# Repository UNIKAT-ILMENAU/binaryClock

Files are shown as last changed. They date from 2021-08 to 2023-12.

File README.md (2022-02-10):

# Notizen

## Idee

- QRCode mit Link auf Webseite für Flackercode Config Tool
- vllt Pads für I2C und ISP rausführen
- auf PCB, welche LED welcher Modus ist
- Comic Design? (muss zu Skyline passen)

## Hardware
- Fotodioden/transistoren
    - SFH 229 OSO
    - SFH 203
    - PT 334-6C EVL
    - SFH 309-5 OSO
    - SFH 300-3/4
- Batteriehalter: https://www.mouser.de/ProductDetail/Linx-Technologies/BAT-HLD-012-SMT?qs=Z0V%2FpEl%252BOGfZsSJil9WIXw%3D%3D
- Micro USB Port: https://www.mouser.de/ProductDetail/CUI-Devices/UJ2-MIBH-G-SMT-TR?qs=IS%252B4QmGtzzpvS1XQusp0iA%3D%3D

## Lötreihenfolge
- Quartz
- Widerstände
- LED
- Taster
- Sockel
- Kondensatoren

## Software
- https://forum.arduino.cc/t/time-libary-sommerzeit-winterzeit/221884

### Modi
Button 1: Select
Button 2: Plus
Button 3: Minus

Select rotiert durch die Zustände, Plus und Minus verändern den Wert

- TimeRunning, Zeit wird angezeigt und zählt          
- MenuYear, Jahr setzen
- MenuMonth, Monat setzen
- MenuDay, Tag setzen
- MenuHour, Stunden setzen
- MenuMinute, Minuten setzen
- MenuSecond, Sekunden setzen 

## ADC Calculation
| No. Switches | 3 | | Button No. | Req'd ADC | Req'd V (R1) | Req'd V (R2+) | Req'd R | Closest R | Actual V (R1) | Actual V (R2+) | Actual ADC | Diff from prev. | In Tolerance | Current (mA) |
|---|---:|---|---:|---:|---:|---:|---:|---:|---:|---:|---:|---:|---:|---:|
| ADC Resolution  | 1024 | | 0 | 1024 | 0.00 | 5.00 | 47000 | 47000 | 5.00 | 0.00 | 0 | 0 | N/A | 0.11 |
| Tolerance (%) | 2 | | 1 | 341 | 3.33 | 1.67 | 23500 | 24000 | 3.31 | 1.69 | 346 | 346 | YES | 0.07 |
| Voltage | 5 | | 2 | 683 | 1.67 | 3.33 | 70500 | 68000 | 1.69 | 3.31 | 678 | 332 | YES | 0.04 |
| | | | 3 | | | | | | | | | | | |
| | | | 4 | | | | | | | | | | | |
| | | | 5 | | | | | | | | | | | |
| | | | 6 | | | | | | | | | | | |
| | | | 7 | | | | | | | | | | | |
| ADC Tolerance | 20.48 |  (+/-) | 8 | | | | | | | | | | | |
| Std. Deviation  | 10.27164132 | | 9 | | | | | | | | | | | |
| | | | 10 | | | | | | | | | | | |
| | | | 11 | | | | | | | | | | | |

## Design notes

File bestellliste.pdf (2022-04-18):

Tabelle1

Seite 1

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

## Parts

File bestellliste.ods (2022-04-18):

Teil | Händler | Händlerbez./Bestellnr. |  | Stückzahl | Kosten pro Shop |  | mit MwSt | Versand
BAT-HLD-012-SMT | Digi-Key | BAT-HLD-012-SMT-ND | -> LINK | 120 | Digi-Key | 393,668 | 468,46492 | 0
ATTINY84V-10PU | Digi-Key | ATTINY84V-10PU-ND | -> LINK | 120 | Highlight-led | 227,63 | 227,63 | 0
Micro-usb-port | Digi-Key | UJ2-MIBH-G-SMT-TR | -> LINK | 120 | Reichelt | 43,8 | 43,8 | 5,59
PT 204-6C | Digi-Key | 1080-1152-ND | -> LINK | 100 | RS | 95,24 | 113,3356 | 0
82Ω Widerstand | Digi-Key | CFM12JT82R0 | -> LINK | 400
4.7kΩ Widerstand | Digi-Key | CFM12JT4K70 | -> LINK | 200
10k | Digi-Key | CFM12JT10K0 | -> LINK | 100
47k | Digi-Key | CFM12JT47K0 | -> LINK | 100 |  | Kosten Gesamt (geschätzt!)
24k | Digi-Key | CFM12JT24K0 | -> LINK | 100 |  | 858,82052
68k | Digi-Key | CFM12JT68K0 | -> LINK | 100
6x6mm Taster | Digi-Key | 2223-TS02-66-50-BK-160-SCR-D-ND | -> LINK | 300
LED | Highlight-led | WTN-5-3600ww | -> LINK | 1700
Mini Quarz | Reichelt | 0,032768 | -> LINK | 100
15pF Kondensator | Reichelt | KERKO-500 15p | -> LINK | 100
100nF Kondensator | Reichelt | HITA SF1H104Z-L5 | -> LINK | 200
Sockel DIL 14 | Reichelt | GS 14 | -> LINK | 120
Sockel DIL 8 | Reichelt | GS 8 | -> LINK | 120
MCP7940N-I/P | RS | 165-2125 | -> LINK | 120
18pF Kondensator | RS | 852-3312 | -> LINK | 100

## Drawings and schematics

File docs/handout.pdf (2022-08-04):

# UNIKAT - Binäruhr

## Widerstände

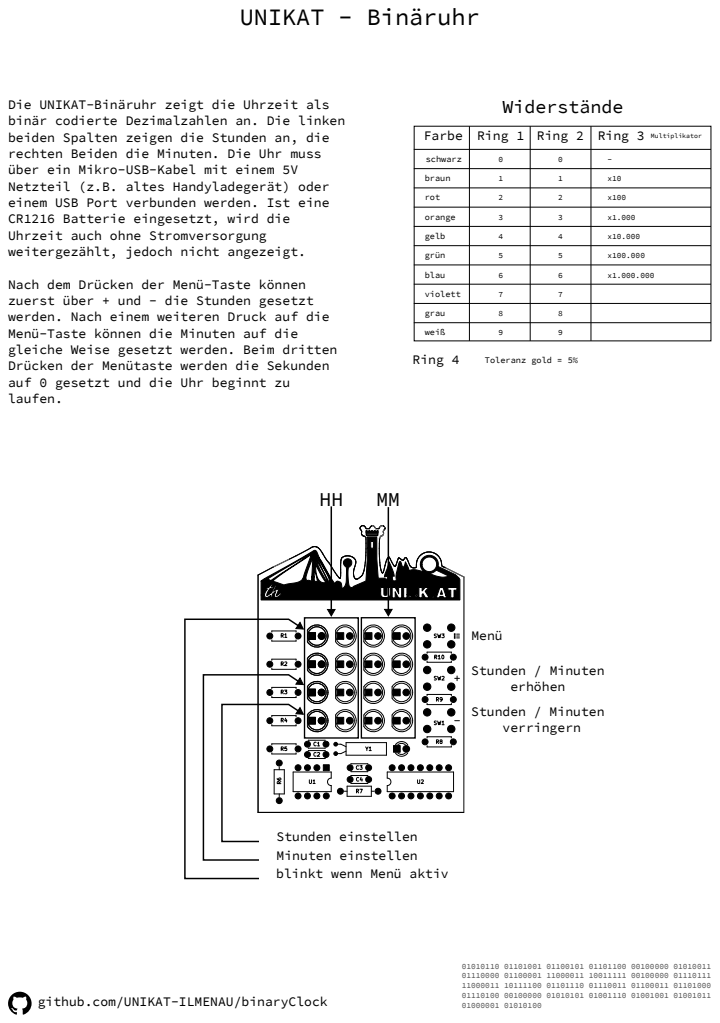
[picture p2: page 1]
Ring 4; Toleranz gold = 5%; Farbe; Ring 1; Ring 2; Multiplikator; schwarz; braun; rot; orange; gelb; grün; blau; violett; grau; weiß; Ring 3; Menü; Stunden / Minuten erhöhen; Stunden / Minuten verringern

Die UNIKAT-Binäruhr zeigt die Uhrzeit als
binär codierte Dezimalzahlen an. Die linken
beiden Spalten zeigen die Stunden an, die
rechten Beiden die Minuten. Die Uhr muss
über ein Mikro-USB-Kabel mit einem 5V
Netzteil (z.B. altes Handyladegerät) oder
einem USB Port verbunden werden. Ist eine
CR1216 Batterie eingesetzt, wird die
Uhrzeit auch ohne Stromversorgung
weitergezählt, jedoch nicht angezeigt.

Nach dem Drücken der Menü-Taste können
zuerst über + und - die Stunden gesetzt
werden. Nach einem weiteren Druck auf die
Menü-Taste können die Minuten auf die
gleiche Weise gesetzt werden. Beim dritten
Drücken der Menütaste werden die Sekunden
auf 0 gesetzt und die Uhr beginnt zu
laufen.

Stunden einstellen
Minuten einstellen
blinkt wenn Menü aktiv

github.com/UNIKAT-ILMENAU/binaryClock

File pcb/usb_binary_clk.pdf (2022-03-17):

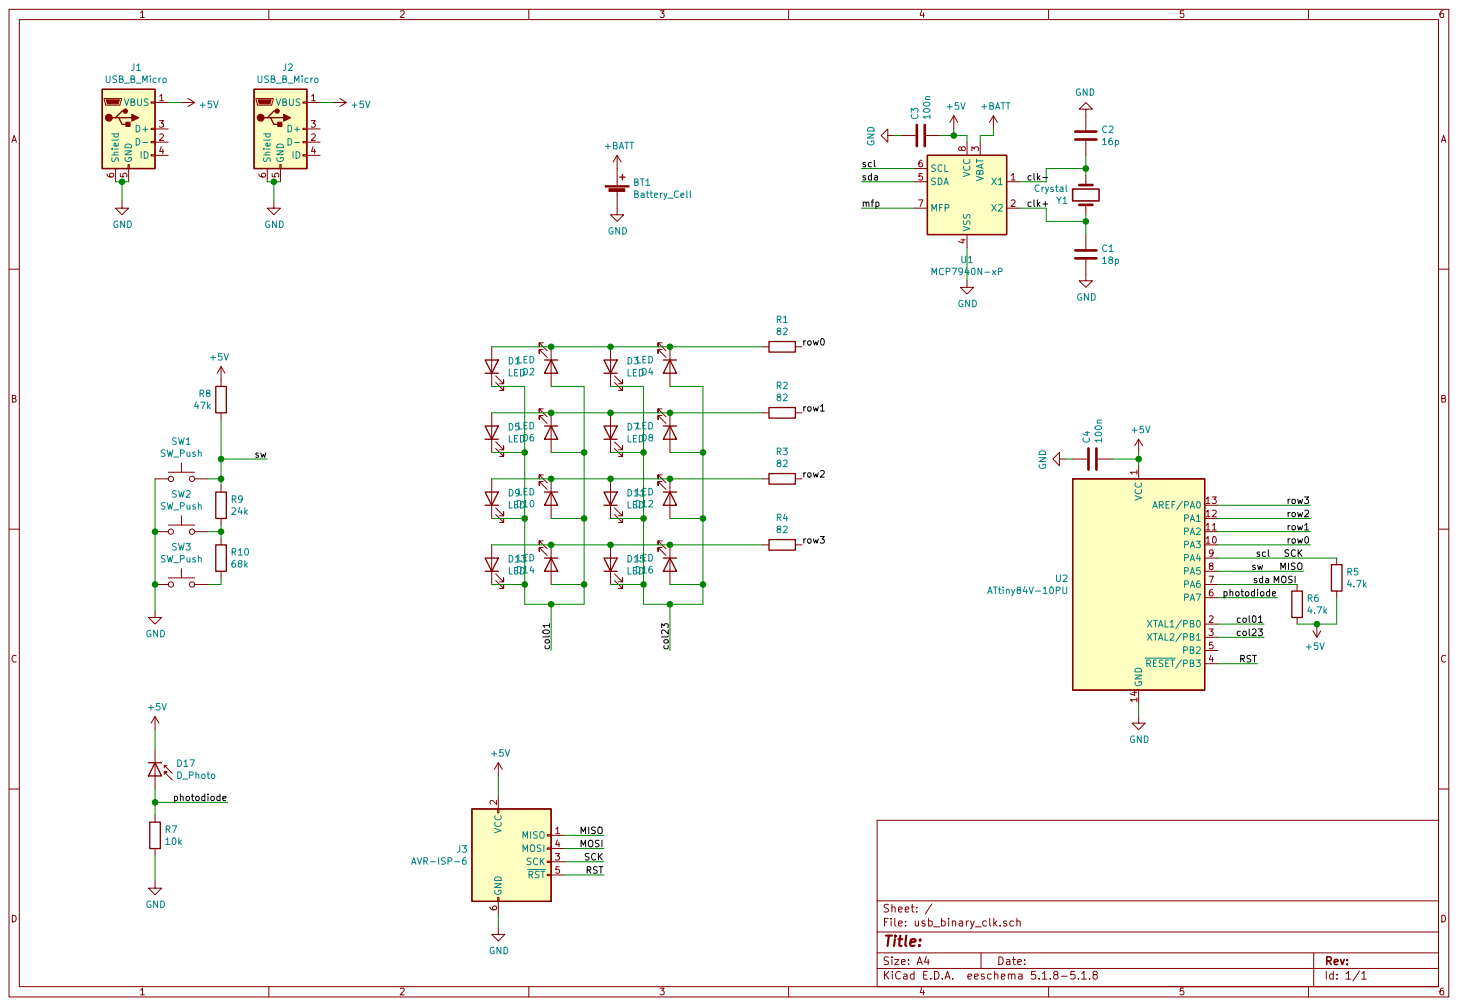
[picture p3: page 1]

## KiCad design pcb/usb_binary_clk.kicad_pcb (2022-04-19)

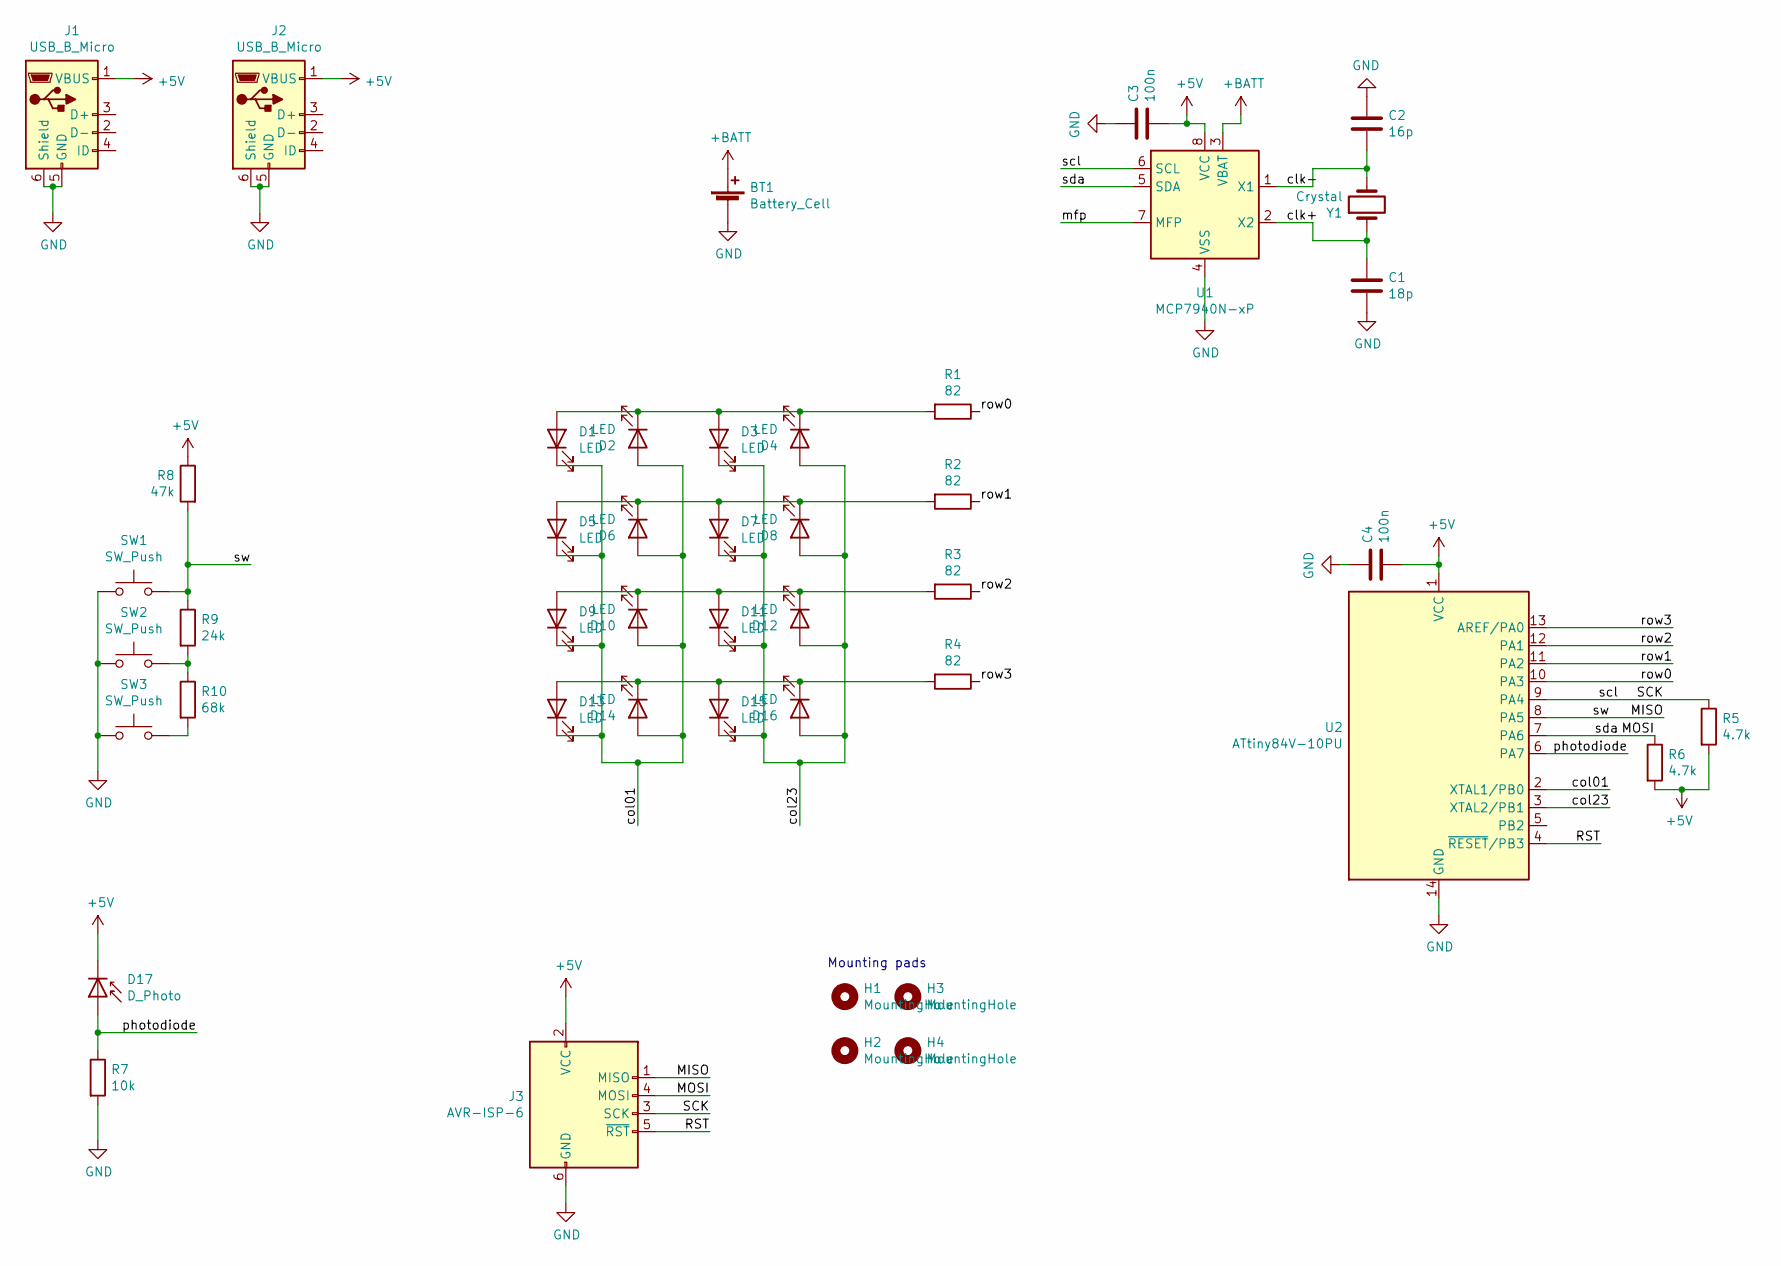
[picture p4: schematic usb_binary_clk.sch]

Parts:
BT1: Battery_Cell; bat-hld-012
C1: 18p; C_Disc_D4.3mm_W1.9mm_P5.00mm
C2: 16p; C_Disc_D4.3mm_W1.9mm_P5.00mm
C3, C4: 100n; C_Disc_D4.3mm_W1.9mm_P5.00mm
D1, D2, D3, D4, D5, D6, D7, D8, D9, D10, D11, D12, D13, D14, D15, D16: LED; LED_D5.0mm
D17: D_Photo; LED_D3.0mm
H1, H2, H3, H4: MountingHole; mountingPad_custom1
J1, J2: USB_B_Micro; UJ2MIBHGSMTTR
J3: AVR-ISP-6; isp_pogoPinPads
R1, R2, R3, R4: 82; R_Axial_DIN0207_L6.3mm_D2.5mm_P7.62mm_Horizontal
R5: 4.7k; R_Axial_DIN0207_L6.3mm_D2.5mm_P7.62mm_Horizontal
R6: 4.7k; R_Axial_DIN0207_L6.3mm_D2.5mm_P10.16mm_Horizontal
R7: 10k; R_Axial_DIN0207_L6.3mm_D2.5mm_P10.16mm_Horizontal
R8: 47k; R_Axial_DIN0207_L6.3mm_D2.5mm_P7.62mm_Horizontal
R9: 24k; R_Axial_DIN0207_L6.3mm_D2.5mm_P7.62mm_Horizontal
R10: 68k; R_Axial_DIN0207_L6.3mm_D2.5mm_P7.62mm_Horizontal
SW1, SW2, SW3: SW_Push; SW_PUSH_6mm_H4.3mm
U1: MCP7940N-xP; DIP-8_W7.62mm
U2: ATtiny84V-10PU; DIP-14_W7.62mm
Y1: Crystal; Crystal_AT310_D3.0mm_L10.0mm_Horizontal

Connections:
+5V: C3.2, C4.2, D17.1 (K), J1.1 (VBUS), J2.1 (VBUS), J3.2 (VCC), R5.2, R6.2, R8.1, U1.8 (VCC), U2.1 (VCC)
+BATT: BT1.1 (+), U1.3 (VBAT)
/MISO: J3.1 (MISO), R8.2, R9.1, SW1.1, U2.8 (PA5)
/MOSI: J3.4 (MOSI), R6.1, U1.5 (SDA), U2.7 (PA6)
/RST: J3.5 (~RST), U2.4 (~RESET~/PB3)
/SCK: J3.3 (SCK), R5.1, U1.6 (SCL), U2.9 (PA4)
/clk+: C1.1, U1.2 (X2), Y1.1
/clk-: C2.2, U1.1 (X1), Y1.2
/col01: D1.1 (K), D2.2 (A), D5.1 (K), D6.2 (A), D9.1 (K), D10.2 (A), D13.1 (K), D14.2 (A), U2.2 (XTAL1/PB0)
/col23: D3.1 (K), D4.2 (A), D7.1 (K), D8.2 (A), D11.1 (K), D12.2 (A), D15.1 (K), D16.2 (A), U2.3 (XTAL2/PB1)
/mfp: U1.7 (MFP)
/photodiode: D17.2 (A), R7.1, U2.6 (PA7)
/row0: R1.1, U2.10 (PA3)
/row1: R2.1, U2.11 (PA2)
/row2: R3.1, U2.12 (PA1)
/row3: R4.1, U2.13 (AREF/PA0)
GND: BT1.2 (-), C1.2, C2.1, C3.1, C4.1, J1.5 (GND), J1.6 (Shield), J2.5 (GND), J2.6 (Shield), J3.6 (GND), R7.2, SW1.2, SW2.2, SW3.2, U1.4 (VSS), U2.14 (GND)
unnamed: D1.2 (A), D2.1 (K), D3.2 (A), D4.1 (K), R1.2
unnamed: D5.2 (A), D6.1 (K), D7.2 (A), D8.1 (K), R2.2
unnamed: D9.2 (A), D10.1 (K), D11.2 (A), D12.1 (K), R3.2
unnamed: D13.2 (A), D14.1 (K), D15.2 (A), D16.1 (K), R4.2
unnamed: R9.2, R10.1, SW2.1
unnamed: R10.2, SW3.1

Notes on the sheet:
Mounting pads

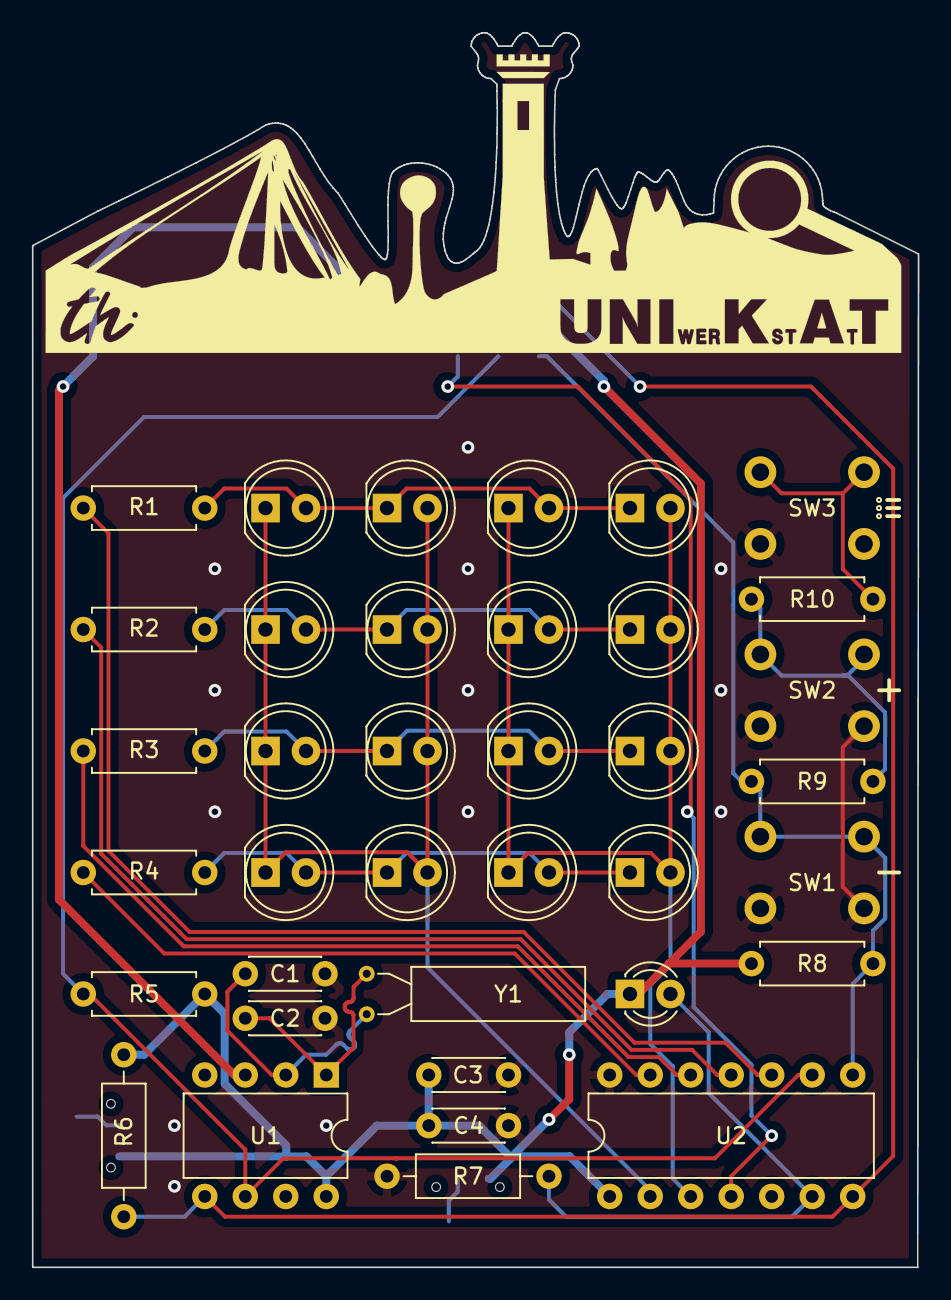
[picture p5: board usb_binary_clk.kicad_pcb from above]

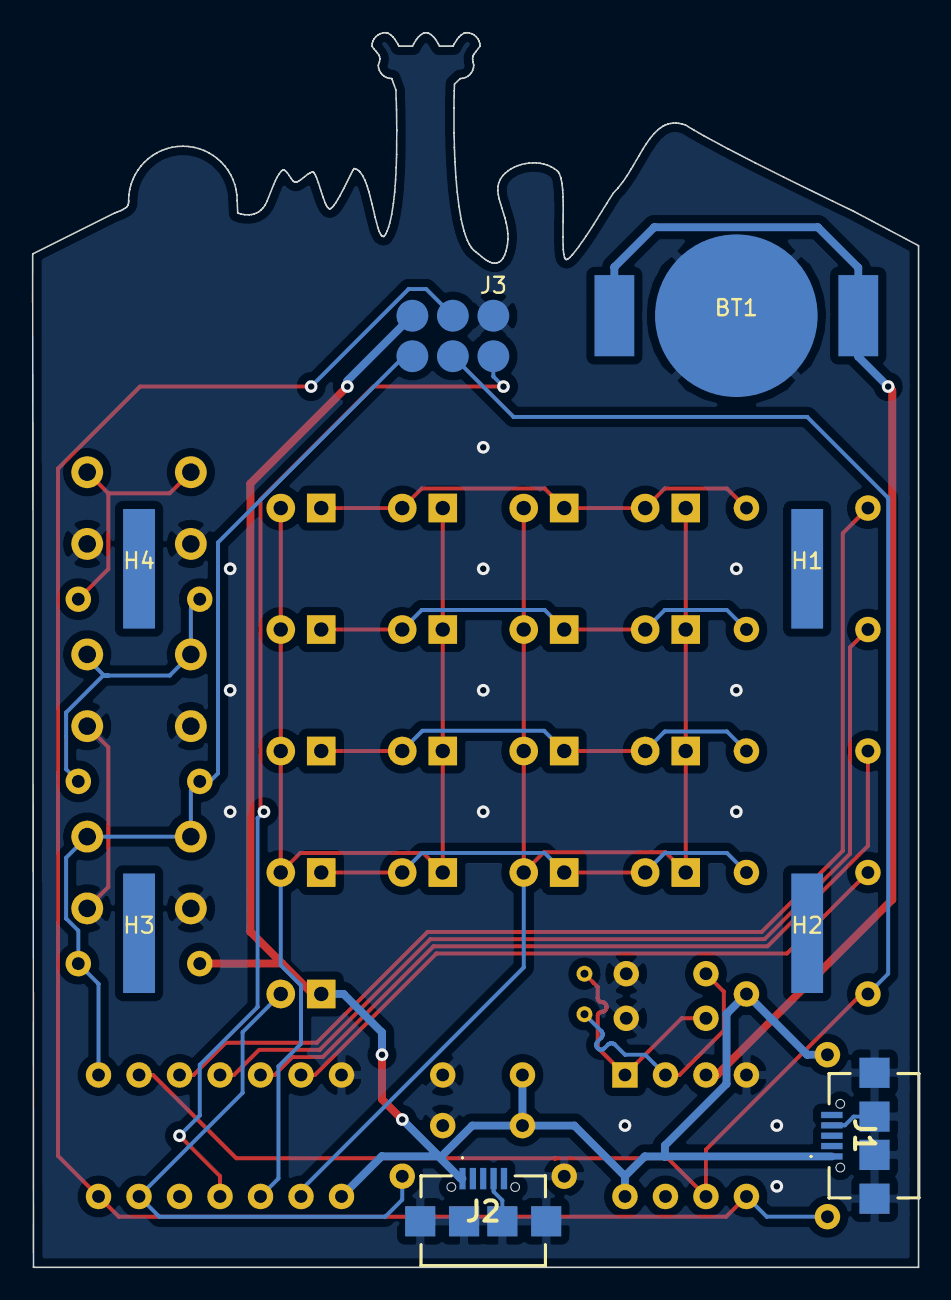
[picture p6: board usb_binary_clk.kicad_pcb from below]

Board: 2 copper layers, 55.6 x 77.4 mm, 45 parts (8 on the bottom side), 22 nets.

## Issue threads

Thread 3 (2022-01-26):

PCB: Quartz nicht fixiert

DirkHeinke, 2022-01-26:
Der Quartz sollte am besten noch mit so einem kleinen Metallbügel festgemacht werden

johnkrmr, 2022-03-24:
Benötigen wir nicht, hält auch so

Closed 2022-03-24.

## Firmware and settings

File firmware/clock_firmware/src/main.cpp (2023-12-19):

/*
USB Binary Clock using ATtin84 and MCP7940

Notes:
timer interrupt generator: https://www.arduinoslovakia.eu/application/timer-calculator

TODO:
- Clock Calibration
*/

#include <Arduino.h>
#include <MCP7940.h>
#include <time.h>

// pinout for pio https://raw.githubusercontent.com/SpenceKonde/ATTinyCore/master/avr/extras/Pinout_x4.jpg
#define ROW0 10
#define ROW1 9
#define ROW2 8
#define ROW3 7
#define COL0 0
#define COL1 1
#define PHOTOTRANSISTOR A7
#define BUTTON_PIN A5
#define BUTTON_1_THRESHOLD 173 // 0
#define BUTTON_2_THRESHOLD 512 // 346
#define BUTTON_3_THRESHOLD 851 // 678

#define BRIGHTNESS_FULL 100
#define BRIGHTNESS_HALF 50
#define BRIGHTNESS_LOW 1

#define THRESHOLD_TO_FULL 512
#define THRESHOLD_FROM_FULL 400
#define THRESHOLD_TO_LOW 1
#define THRESHOLD_FROM_LOW 100

#define LEDS_UPDATE_INTERVAL_MS 100
#define BUTTON_DEBOUNCE_MS 50
#define BUTTON_HOLD_MS 500

enum ClockStates
{
  TimeRunning,
  MenuYear = 11,
  MenuMonth = 12,
  MenuDay = 13,
  MenuHour = 1,
  MenuMinute = 2,
  MenuSecond = 6,
};

enum Buttons
{
  ButtonNone,
  ButtonSelect,
  ButtonPlus,
  ButtonMinus,
  ButtonError
};

int const COL[] = {COL0, COL1};
int const ROW[] = {ROW0, ROW1, ROW2, ROW3};

uint8_t columnCounter = 0;
uint8_t pwmCounter = 0;
uint8_t displayBrightness = BRIGHTNESS_HALF;

uint8_t columnValues[4] = {0};

enum ClockStates clockState = TimeRunning;

Buttons lastButton = ButtonNone;
unsigned long tLastUpdateTimer = 0;
unsigned long tLastButtonTimer = 0;
tm theTimeWeWantToSet;

// MCP7940 object
MCP7940_Class MCP7940;

void calculatedFrequency();
void displayIntAsBCD(uint16_t val);

void setupTimer1()
{
  noInterrupts();
  // Clear registers
  TCCR1A = 0;
  TCCR1B = 0;
  TCNT1 = 0;

  // 40000 Hz (8000000/((24+1)*8))
  OCR1A = 24;
  // CTC
  TCCR1B |= (1 << WGM12);
  // Prescaler 8
  TCCR1B |= (1 << CS11);
  // Output Compare Match A Interrupt Enable
  TIMSK1 |= (1 << OCIE1A);
  interrupts();
}

tm dateTimeToTm(DateTime dateTime)
{
  tm time;
  time.tm_sec = dateTime.second();
  time.tm_min = dateTime.minute();
  time.tm_hour = dateTime.hour();
  time.tm_mday = dateTime.day();
  time.tm_mon = dateTime.month();
  time.tm_year = dateTime.year();
  return time;
}

DateTime tmToDateTime(tm time)
{
  return DateTime(time.tm_year, time.tm_mon, time.tm_mday, time.tm_hour, time.tm_min, time.tm_sec);
}

ClockStates stateFunction(Buttons buttons) // fix return type
{
  switch (clockState)
  {
  case TimeRunning:
    if (buttons == ButtonSelect)
    {
      theTimeWeWantToSet = dateTimeToTm(MCP7940.now());
      theTimeWeWantToSet.tm_sec = 0; // reset seconds to zero, because the user can not set them :(
      clockState = MenuHour;
    }
    break;
  case MenuYear:
    if (buttons == ButtonSelect)
    {
      clockState = MenuMonth;
    }
    else if (buttons == ButtonPlus)
    {
      theTimeWeWantToSet.tm_yday++;
    }
    else if (buttons == ButtonMinus)
    {
      theTimeWeWantToSet.tm_yday--;
    }
    break;
  case MenuMonth:
    if (buttons == ButtonSelect)
    {
      clockState = MenuDay;
    }
    else if (buttons == ButtonPlus)
    {
      theTimeWeWantToSet.tm_mon++;
      if (theTimeWeWantToSet.tm_mon > 11)
      {
        theTimeWeWantToSet.tm_mon = 0;
      }
    }
    else if (buttons == ButtonMinus)
    {
      theTimeWeWantToSet.tm_mon--;
      if (theTimeWeWantToSet.tm_mon < 0)
      {
        theTimeWeWantToSet.tm_mon = 11;
      }
    }
    break;
  case MenuDay:
    if (buttons == ButtonSelect)
    {
      clockState = MenuHour;
    }
    else if (buttons == ButtonPlus)
    {
      // TODO check if < 31 in that month/year
      theTimeWeWantToSet.tm_mday++;
      if (theTimeWeWantToSet.tm_mday > 31)
      {
        theTimeWeWantToSet.tm_mday = 1;
      }
    }
    else if (buttons == ButtonMinus)
    {
      // TODO check if < 31 in that month/year
      theTimeWeWantToSet.tm_mday--;
      if (theTimeWeWantToSet.tm_mday < 1)
      {
        theTimeWeWantToSet.tm_mday = 31;
      }
    }
    break;
  case MenuHour:
    if (buttons == ButtonSelect)
    {
      clockState = MenuMinute;
    }
    else if (buttons == ButtonPlus)
    {
      theTimeWeWantToSet.tm_hour++;
      if (theTimeWeWantToSet.tm_hour > 23)
      {
        theTimeWeWantToSet.tm_hour = 0;
      }
    }
    else if (buttons == ButtonMinus)
    {
      theTimeWeWantToSet.tm_hour--;
      if (theTimeWeWantToSet.tm_hour < 0)
      {
        theTimeWeWantToSet.tm_hour = 23;
      }
    }
    break;
  case MenuMinute:
    if (buttons == ButtonSelect)
    {
      MCP7940.adjust(tmToDateTime(theTimeWeWantToSet));
      clockState = TimeRunning; // skip seconds :(
    }
    else if (buttons == ButtonPlus)
    {
      theTimeWeWantToSet.tm_min++;
      if (theTimeWeWantToSet.tm_min > 59)
      {
        theTimeWeWantToSet.tm_min = 0;
      }
    }
    else if (buttons == ButtonMinus)
    {
      theTimeWeWantToSet.tm_min--;
      if (theTimeWeWantToSet.tm_min < 0)
      {
        theTimeWeWantToSet.tm_min = 59;
      }
    }
    break;
  case MenuSecond:
    // not implemented
    break;

  default:
    break;
  }
}

void getTimeAndWriteToLeds()
{
  static uint8_t secs;          // store the seconds value
  DateTime now = MCP7940.now(); // get the current time
  if (secs != now.second())
  { // Output if seconds have changed
    //  now.hour();
    //  now.minute();

    columnValues[3] = now.minute() % 10;
    columnValues[2] = now.minute() / 10;
    columnValues[1] = now.hour() % 10;
    columnValues[0] = now.hour() / 10;
    secs = now.second();
  }
}

void getBrightnessAndWriteToLed()
{
  uint16_t val = analogRead(PHOTOTRANSISTOR);
  uint8_t val1 = val % 10;
  uint8_t val10 = (val % 100) / 10;
  uint8_t val100 = (val % 1000) / 100;
  uint8_t val1000 = val / 1000;
  columnValues[0] = val1000;
  columnValues[1] = val100;
  columnValues[2] = val10;
  columnValues[3] = val1;
}

// based on state, set colums to display
void setColumValues()
{
  switch (clockState)
  {
  case TimeRunning:
    getTimeAndWriteToLeds();
    // getBrightnessAndWriteToLed();
    break;
  case MenuYear:
    columnValues[0] = MenuYear;
    columnValues[1] = 0;
    columnValues[2] = theTimeWeWantToSet.tm_year / 10;
    columnValues[3] = theTimeWeWantToSet.tm_year % 10;
    break;
  case MenuMonth:
    columnValues[0] = MenuMonth;
    columnValues[1] = 0;
    columnValues[2] = theTimeWeWantToSet.tm_mon / 10;
    columnValues[3] = theTimeWeWantToSet.tm_mon % 10;
    break;
  case MenuDay:
    columnValues[0] = MenuDay;
    columnValues[1] = 0;
    columnValues[2] = theTimeWeWantToSet.tm_mday / 10;
    columnValues[3] = theTimeWeWantToSet.tm_mday % 10;
    break;
  case MenuHour:
    columnValues[0] = MenuHour;
    columnValues[1] = 0;
    columnValues[2] = theTimeWeWantToSet.tm_hour / 10;
    columnValues[3] = theTimeWeWantToSet.tm_hour % 10;
    break;
  case MenuMinute:
    columnValues[0] = MenuMinute;
    columnValues[1] = 0;
    columnValues[2] = theTimeWeWantToSet.tm_min / 10;
    columnValues[3] = theTimeWeWantToSet.tm_min % 10;
    break;
  case MenuSecond:
    columnValues[0] = MenuSecond;
    columnValues[1] = 0;
    columnValues[2] = theTimeWeWantToSet.tm_sec / 10;
    columnValues[3] = theTimeWeWantToSet.tm_sec % 10;
    break;

  default:
    break;
  }
  static bool blink = false; // assigns value of 5 only once
  if (clockState != TimeRunning)
  {
    static long tBlinkLast = 0;
    long tBlinkNow = millis();
    if (tBlinkNow - tBlinkLast >= 250)
    {
      blink = !blink;
      tBlinkLast = tBlinkNow;
    }
  }
  else
  {
    blink = false;
  }
  if (blink)
  {
    columnValues[0] |= 0b1000;
  }
  else
  {
    columnValues[0] &= 0b0111;
  }
}

void setDisplayBrightnes()
{
  uint16_t brightness = analogRead(PHOTOTRANSISTOR);
  if (displayBrightness == BRIGHTNESS_FULL)
  {
    if (brightness <= THRESHOLD_FROM_FULL)
    {
      displayBrightness = BRIGHTNESS_HALF;
    }
  }
  else if (displayBrightness == BRIGHTNESS_HALF)
  {
    if (brightness >= THRESHOLD_TO_FULL)
    {
      displayBrightness = BRIGHTNESS_FULL;
    }
    else if (brightness <= THRESHOLD_TO_LOW)
    {
      displayBrightness = BRIGHTNESS_LOW;
    }
  }
  else if (displayBrightness == BRIGHTNESS_LOW)
  {
    if (brightness >= THRESHOLD_FROM_LOW)
    {
      displayBrightness = BRIGHTNESS_HALF;
    }
  }
}

bool lastPhotValWasHigh = 0;
uint16_t lastPhotoVal = 0;
unsigned long lastPhotoChangedMs = 0;
#define PHOTO_TH 50

void calculatedFrequency()
{
  uint16_t val = analogRead(PHOTOTRANSISTOR);
  if (val < PHOTO_TH && lastPhotValWasHigh)
  {
    unsigned long now = millis();
    unsigned long msBetweenFallingEdge = now - lastPhotoChangedMs;
    int frequency = 1.0 / (msBetweenFallingEdge / 1000.0);
    displayIntAsBCD(frequency);
    lastPhotoChangedMs = now;
    lastPhotValWasHigh = false;
  }
  else if (val > PHOTO_TH)
  {
    lastPhotValWasHigh = true;
  }
}

void displayIntAsBCD(uint16_t val)
{
  uint8_t val1 = val % 10;
  uint8_t val10 = (val % 100) / 10;
  uint8_t val100 = (val % 1000) / 100;
  uint8_t val1000 = val / 1000;
  columnValues[0] = val1000;
  columnValues[1] = val100;
  columnValues[2] = val10;
  columnValues[3] = val1;
}

// set column col according to binary patter columnValue
void setCol(uint8_t col, uint8_t columnValue)
{
  // set rows to floating
  DDRA &= 0b11110000;

  // set columns to floating
  // pinMode(COL0, INPUT);
  // pinMode(COL1, INPUT);
  // in fast:
  DDRB &= 0b11111100;
  PORTB &= 0b11111100; // Remove pullups

  if (col % 2 == 0)
  {
    PORTA &= 0b11110000;               // turn off pin0-3
    PORTA |= columnValue & 0b00001111; // turn on pin0-3 where columnValue is 1
  }
  else
  {
    PORTA |= 0b00001111;                  // turn on pin0-3
    PORTA &= ~(columnValue & 0b00001111); // turn off pin0-3 where columeValue is 1

    // Beispielrechnung
    // dddd 1010 & 0000 1111 = 0000 1010
    //           ~ 0000 1010 = 1111 0101
    // dddd 1111 & 1111 0101 = dddd 0101
  }

  if (col == 0)
  {
    // pinMode(COL0, OUTPUT);
    // digitalWrite(COL0, LOW);
    // in fast:
    PORTB &= 0b11111110;
    DDRB |= 0b00000001;
  }
  else if (col == 1)
  {
    // digitalWrite(COL0, HIGH);
    // pinMode(COL0, OUTPUT);
    // in fast:
    PORTB |= 0b00000001;
    DDRB |= 0b00000001;
  }
  else if (col == 2)
  {
    // pinMode(COL1, OUTPUT);
    // digitalWrite(COL1, LOW);
    // in fast:
    PORTB &= 0b11111101;
    DDRB |= 0b00000010;
  }
  else if (col == 3)
  {
    // digitalWrite(COL1, HIGH);
    // pinMode(COL1, OUTPUT);
    // in fast:
    PORTB |= 0b00000010;
    DDRB |= 0b00000010;
  }
  // set rows to output
  DDRA |= 0b00001111;
}

void turnOffLeds()
{
  // set rows to floating
  DDRA &= 0b11110000;

  // set columns to floating
  // pinMode(COL0, INPUT);
  // pinMode(COL1, INPUT);
  // in fast:
  DDRB &= 0b11111100;
  PORTB &= 0b11111100; // Remove pullups
  // turn off pin0-3
  PORTA &= 0b11110000;
  // set rows to output
  DDRA |= 0b00001111;
}

Buttons getButtons()
{
  uint16_t read = analogRead(BUTTON_PIN);
  uint16_t read2 = analogRead(BUTTON_PIN);
  if(abs(read - read2)>3){
    return ButtonError;
  }
  if (read < BUTTON_1_THRESHOLD)
  {
    return ButtonMinus;
  }
  if (read < BUTTON_2_THRESHOLD)
  {
    return ButtonPlus;
  }
  if (read < BUTTON_3_THRESHOLD)
  {
    return ButtonSelect;
  }
  return ButtonNone; // Kein Button gedrückt
}

void setup()
{
  pinMode(ROW0, OUTPUT);
  pinMode(ROW1, OUTPUT);
  pinMode(ROW2, OUTPUT);
  pinMode(ROW3, OUTPUT);
  pinMode(COL0, OUTPUT);
  pinMode(COL1, OUTPUT);
  pinMode(BUTTON_PIN, INPUT);
  pinMode(PHOTOTRANSISTOR, INPUT);
  setupTimer1();

  while (!MCP7940.begin())
  {
    delay(1);
  }
  MCP7940.deviceStart();
  MCP7940.setBattery(true);
}

void loop()
{
  unsigned long tCurrentTime = millis();

  Buttons readButton = getButtons();
  if (readButton == ButtonError)
  {
    return;
  }

  if (readButton != lastButton || tCurrentTime - tLastButtonTimer > BUTTON_HOLD_MS)
  {
    stateFunction(readButton);
    lastButton = readButton;
    tLastButtonTimer = tCurrentTime;
  }

  if (tCurrentTime - tLastUpdateTimer > LEDS_UPDATE_INTERVAL_MS)
  {
    setColumValues();
    setDisplayBrightnes();
    tLastUpdateTimer = tCurrentTime;
  }
}

ISR(TIMER1_COMPA_vect)
{
  if (pwmCounter == 0 && displayBrightness != 0)
  {
    setCol(columnCounter, columnValues[columnCounter]);
    ++columnCounter;
    if (columnCounter == 4)
    {
      columnCounter = 0;
    }
  }
  if (pwmCounter == displayBrightness)
  {
    turnOffLeds();
  }

  ++pwmCounter;

  if (pwmCounter >= 100)
  {
    pwmCounter = 0;
  }
}

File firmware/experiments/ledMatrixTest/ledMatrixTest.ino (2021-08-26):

#define ROW0 0
#define ROW1 1
#define ROW2 2
#define ROW3 3
#define COL0 7
#define COL1 10
#define COL2 9
#define COL3 8

const int COL[] = {COL0, COL1, COL2, COL3};
const int ROW[] = {ROW0, ROW1, ROW2, ROW3};

void setup() {
  pinMode(ROW0, OUTPUT);
  pinMode(ROW1, OUTPUT);
  pinMode(ROW2, OUTPUT);
  pinMode(ROW3, OUTPUT);
  pinMode(COL0, OUTPUT);
  pinMode(COL1, OUTPUT);
  pinMode(COL2, OUTPUT);
  pinMode(COL3, OUTPUT);
}



void setCol(uint8_t col, uint8_t y) {
  digitalWrite(COL0, HIGH);
  digitalWrite(COL1, HIGH);
  digitalWrite(COL2, HIGH);
  digitalWrite(COL3, HIGH);

  digitalWrite(COL[col], LOW);
  
  digitalWrite(ROW0, y&0b0001);
  digitalWrite(ROW1, y&0b0010);
  digitalWrite(ROW2, y&0b0100);
  digitalWrite(ROW3, y&0b1000);
  
}

void loop() {
  setCol(0, 0b1010); 
  setCol(1, 0b1010);
  setCol(2, 0b1010); 
  setCol(3, 0b1010);
  //setCol(0, 0b0000);
  //delay(10);
}

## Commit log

2021-08-19 renamed pcb folder
    [usb_binary_clk.kicad_pcb, usb_binary_clk.sch]
2021-08-19 added part values, shold be done
    [usb_binary_clk.sch]
2021-08-19 resistor ladder fixed
    [usb_binary_clk.sch]
2021-08-26 added schematic pdf
2021-08-26 Add led matrix test arduino code
2021-10-16 Read buttons when changed or hold with debounce and update leds faster
2021-10-28 Remove glow in leds by optimising port writes
2021-10-28 Improved led matrix to use up less pins
    [usb_binary_clk.sch]
2021-10-31 Make pwm better
2021-10-31 added phototransistor
    [usb_binary_clk.sch]
2021-11-07 Display, Frequency, schematic fix, ideas, led components
    [usb_binary_clk.sch]
2021-11-18 linked symbols to footprints, started arranging/modding them
    [usb_binary_clk.kicad_pcb, usb_binary_clk.sch]
2021-11-18 Modify pcb layout
    [usb_binary_clk.kicad_pcb, usb_binary_clk.sch]
2021-11-25 add pcb skyline + logos
    [layout.kicad_pcb]
2021-12-02 fix pcb design
    [layout.kicad_pcb, usb_binary_clk.kicad_pcb]
2021-12-02 fix pcb design (for real this time)
    [usb_binary_clk.kicad_pcb]
2021-12-02 finalizes part position
    [usb_binary_clk.kicad_pcb, usb_binary_clk.sch]
2021-12-09 fix broken schematic symbols
    [usb_binary_clk.sch]
2021-12-09 change usb port footprints, add programmer pads
    [usb_binary_clk.kicad_pcb, usb_binary_clk.sch]
2021-12-16 add routing
    [usb_binary_clk.kicad_pcb]
2021-12-16 add routing (forgot to save last time)
    [usb_binary_clk.kicad_pcb]
2022-01-06 tune crystal paths, add vias
    [usb_binary_clk.kicad_pcb]
2022-01-13 rearrange footprint references + add icons
    [usb_binary_clk.kicad_pcb, usb_binary_clk.sch]
2022-01-13 connect programmer; add qr code; create gerber files for first order
    [usb_binary_clk-B_Cu.gbl, usb_binary_clk-B_Mask.gbs, usb_binary_clk-B_Paste.gbp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]
2022-01-13 safety commit
    [usb_binary_clk.kicad_pcb]
2022-02-10 Add brightness control, remove OLED code, swap menu buttons
    [main.cpp]
2022-03-17 update schematic pdf
2022-03-24 move via out of printed part
    fix #4
    [usb_binary_clk.kicad_pcb]
2022-03-24 add mounting pads for stand/wall mount
    fix #7
    [usb_binary_clk.kicad_pcb, usb_binary_clk.sch]
2022-04-04 add ordering excel sheet
    [bestellliste.ods]
2022-04-18 update bestellliste and add pdf version
    [bestellliste.ods]
2022-04-18 attempt to compensate for printing errors in silk screen
    [layout.kicad_pcb, usb_binary_clk.kicad_pcb]
2022-04-18 update gerber files
    [usb_binary_clk-B_Cu.gbl, usb_binary_clk-B_Mask.gbs, usb_binary_clk-B_Paste.gbp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]
2022-04-18 update gerber files (again)
    [usb_binary_clk-B_Cu.gbl, usb_binary_clk-B_Mask.gbs, usb_binary_clk-B_Paste.gbp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]
2022-04-19 Revert "update gerber files (again)"
    This reverts commit 1e2eee7170581ef00778106c54266a2a04ba0844.
    [usb_binary_clk-B_Cu.gbl, usb_binary_clk-B_Mask.gbs, usb_binary_clk-B_Paste.gbp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]
2022-04-19 fix silkscreen printing issues
    close #5
2022-04-19 change photodiode footprint to 3mm
    [usb_binary_clk.kicad_pcb, usb_binary_clk.sch]
2022-04-19 update gerbers for ordering
    [usb_binary_clk-B_Cu.gbl, usb_binary_clk-B_Mask.gbs, usb_binary_clk-B_Paste.gbp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]
2022-04-19 remove back silkscreen file from gerbers
    [usb_binary_clk-B_SilkS.gbo]
2022-06-16 fix fuses
2022-07-14 display hours and minutes; add blinking led in menu
2022-08-03 Fix LED description
2022-08-03 Fix ghost button presses
    [main.cpp]
2022-08-05 fix false button presses
    [main.cpp]
2022-08-05 add notes in schematic
    [usb_binary_clk.sch]
2023-11-12 Enable battery backup on MCP
